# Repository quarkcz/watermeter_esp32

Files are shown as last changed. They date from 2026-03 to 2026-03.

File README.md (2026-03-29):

# Watermeter ESP32 C3
Water meter based on ESP32-C3 - connected to sensor with impulse output.

Published under **[CC BY-NC 4.0](https://creativecommons.org/licenses/by-nc/4.0/legalcode.txt)**

This project was created to have home-made water metering based on [Mikromarz pulse sensor](https://www.mikromarz.com/www-mikromarz-cz/eshop/50-1-Vodomery/172-1-Bytove-vodomery/5/898-Impulsni-modul-pro-vodomery-ENBRA-ER-AM). This sensor requires 5V input, sends a 3.3V logic output signal and is built as open-drain solution (standard output is 3.3V, when impulse, output pin is pulled to GND). If you have a different sensor, feel free to adjust the input part/code. If you have the same one, I recommend to do at least the basic input filtering as I did - tested for several months and works perfect. To have a full control over collected data, software in ESP is not calling directly HomeAssistant, but customizable API. In my case I have a PHP script on my VPS that water meter ESP is connecting to. This PHP script stores the data to MySQL database, where it's read by another PHP script returning raw data and with Python script I get finally a JSON for my HomeAssistant. **Sorry for the complicated architecture - you can of course make it easier - I've used already existing platforms I have access to and since my original solution was connected to Mikromarz cloud, I've reused part of the code reading from the original cloud.**

```
Architecture:
Water sensor -> Water meter -> PHP API -> MySQL -> PHP script -> Python script ->  Home Assistant
```

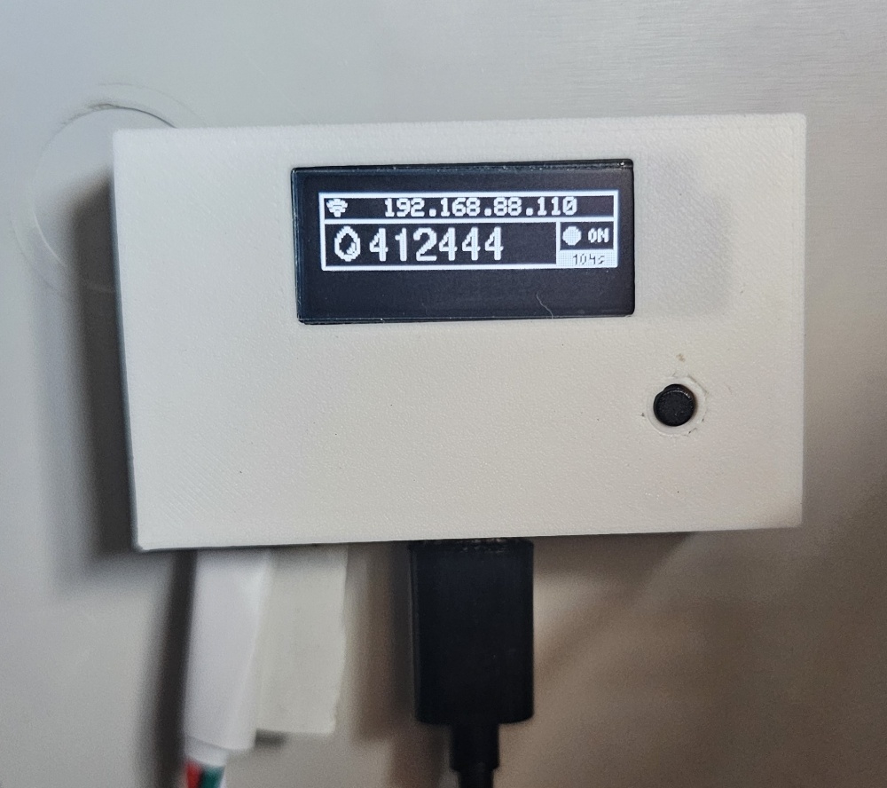
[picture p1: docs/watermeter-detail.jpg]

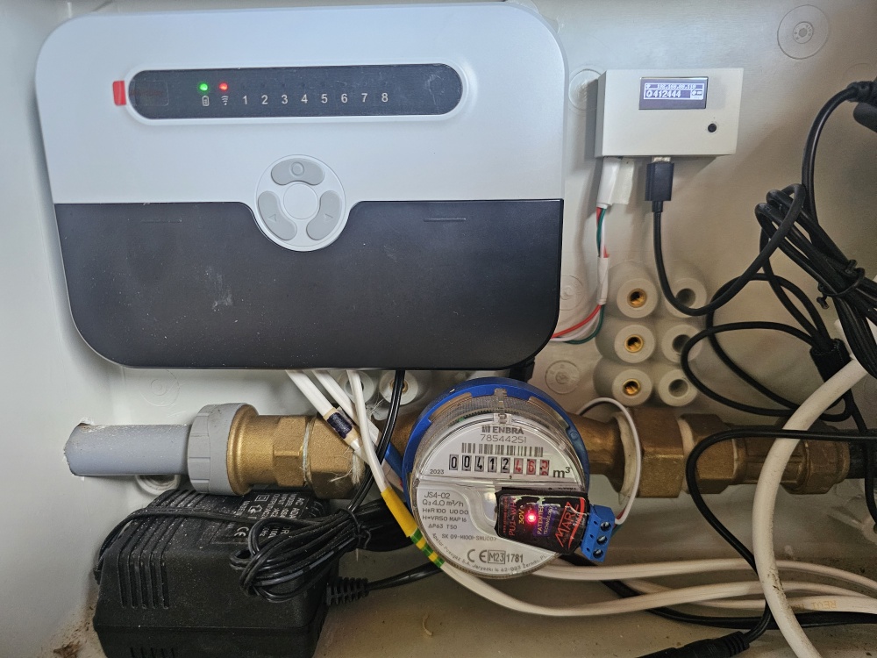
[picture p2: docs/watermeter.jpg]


## Required components
* [ESP32 C3 Zero](https://es.aliexpress.com/item/1005006583420105.html)
* [OLED display 0.91"](https://es.aliexpress.com/item/1005008918700196.html)
* Resistors 1k&Omega;, 10k&Omega;
* Capacitor 100nF
* [Micropush button 6x6x12](https://es.aliexpress.com/item/1005006046180384.html)
* Wires

## Flashing ESP32
Code is written with Arduino architecture, but I've used VS Code with PlatformIO to upload it. LittleFS is used for storing HTML and CSS
1. General -> Full Clean
2. General -> Build (to test if your libraries and dependencies downloaded)
3. Platform -> Build file system image
4. Platform -> Upload file system image
5. Update source code `src/main.cpp` based on your needs (default server/api/...)
6. Build and upload code

## HW assembly
After the firmware upload, disconnect ESP32 and it's time to make HW part.
Ideally print the Enclosure from [3D model published in 3MF](3d/Watermeter%20ESP32%20C3%20zero%20box.3mf). 
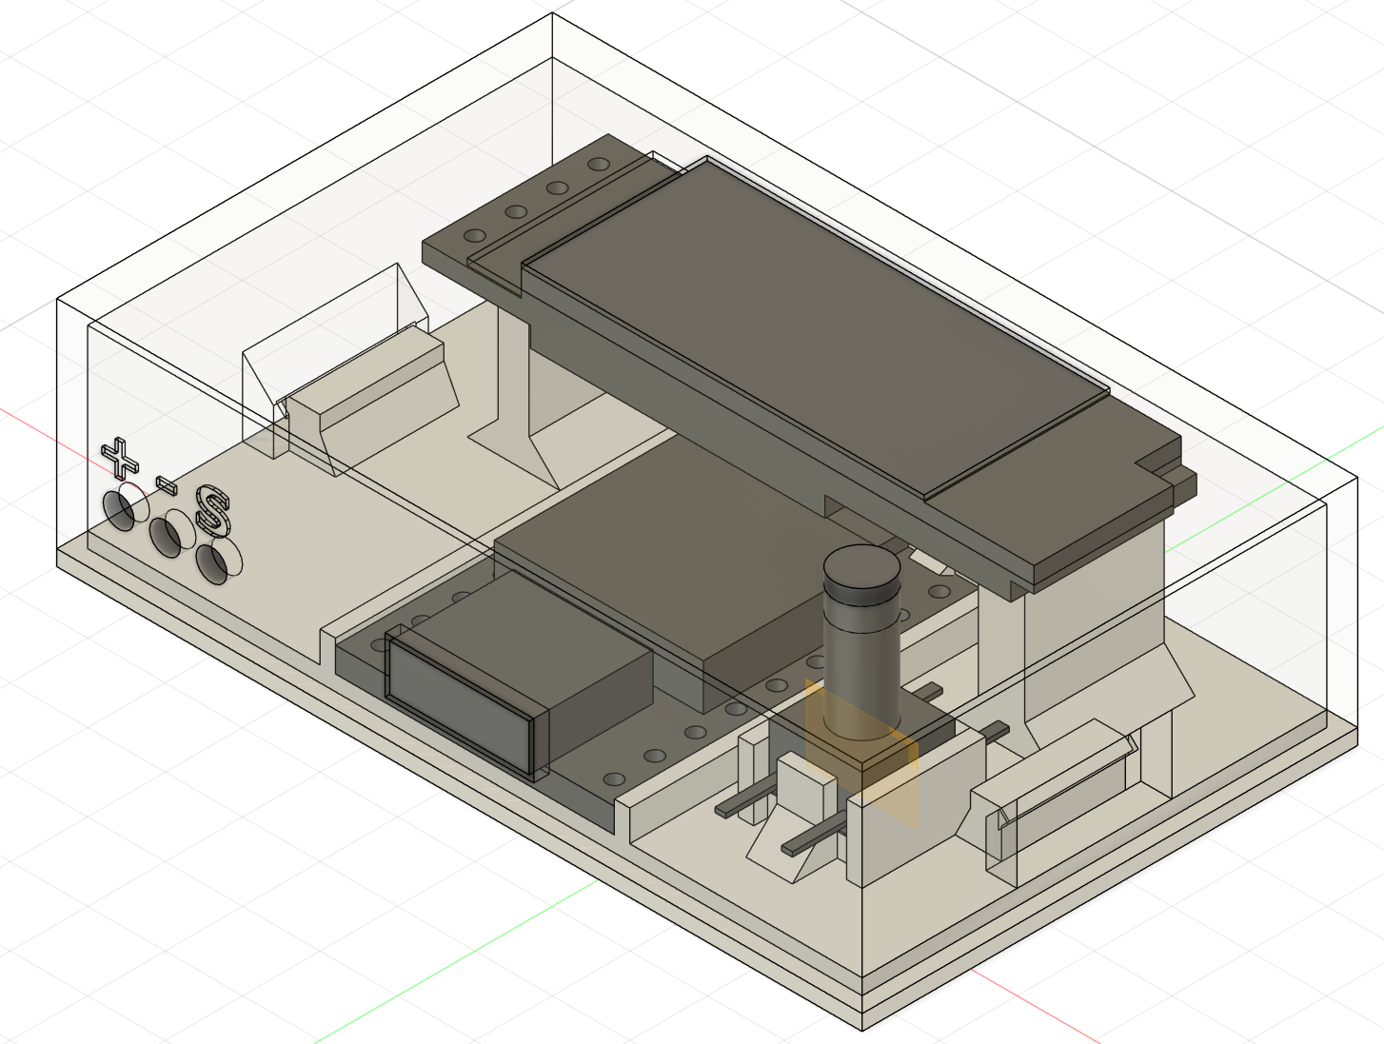
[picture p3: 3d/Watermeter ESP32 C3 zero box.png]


Overall schematics:
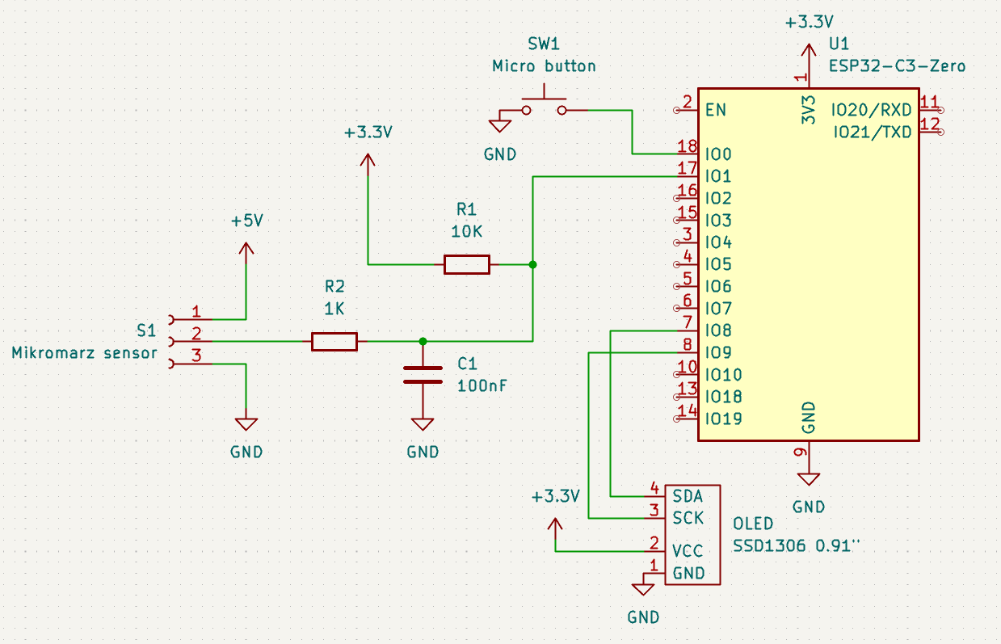
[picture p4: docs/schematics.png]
HW schematics


For filtering input signals - eliminating ghost readings, one of the working (tested) methods is to use schematics ^^^. For connecting the HW, you need to solder two resistors and capacitor + connect the display and microbutton. One of the possible ways that'll fit into the 3D model minimalistic box:

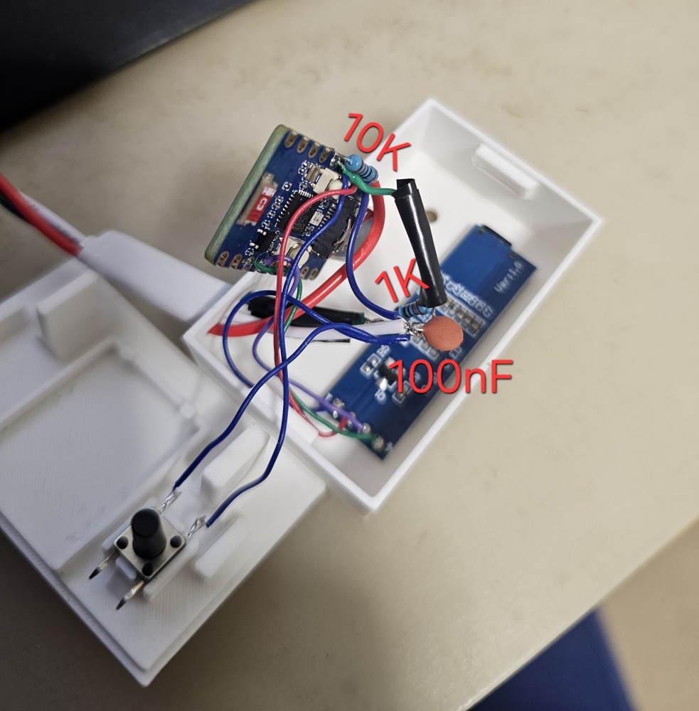
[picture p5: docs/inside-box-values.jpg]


Connection to Mikromarz sensor is simple:
* 5V from ESP32 USB
* GND connected to ESP32 GND
* Pulse connected to 1k resistor (see schematics)

## API part (PHP + MySQL/MariaDB + Python)
For API, I've used simple MySQL/MariaDB tables and PHP script to write data and to read data. Then Python script to return JSON for Home Assistant. 
1. On your server create database for sensors ([table structures](php/sensors-db-structure.sql))
2. Update credentials in PHP scripts `php/sensor-data.php` and `php/sensor-read.php` (in both scripts `mysqli('localhost', 'db_user', 'db_pass', 'db_name');`)
3. Configure your HTML server (i.e. Apache) to execute PHP scripts
4. Create alias for Python script (+ setup webserver to execute Python). For Apache, configuration is like this
````
  <Directory /var/www/html/voda>
    WSGIApplicationGroup %{GLOBAL}
    Order deny,allow
    allow from all	
  </Directory>
  WSGIScriptAlias /voda_spotreba /var/www/html/voda/spotreba.py
````

## First run
If you did everything correctly, after a first run (USB connected), the display will show you SSID and Password for Wifi to connect to. Use your phone/computer to connect to this network and setup your home wifi. After that, you'll see assigned IP on the display.
Connect to this IP and finish the setup - set parameters for API, keys, ...
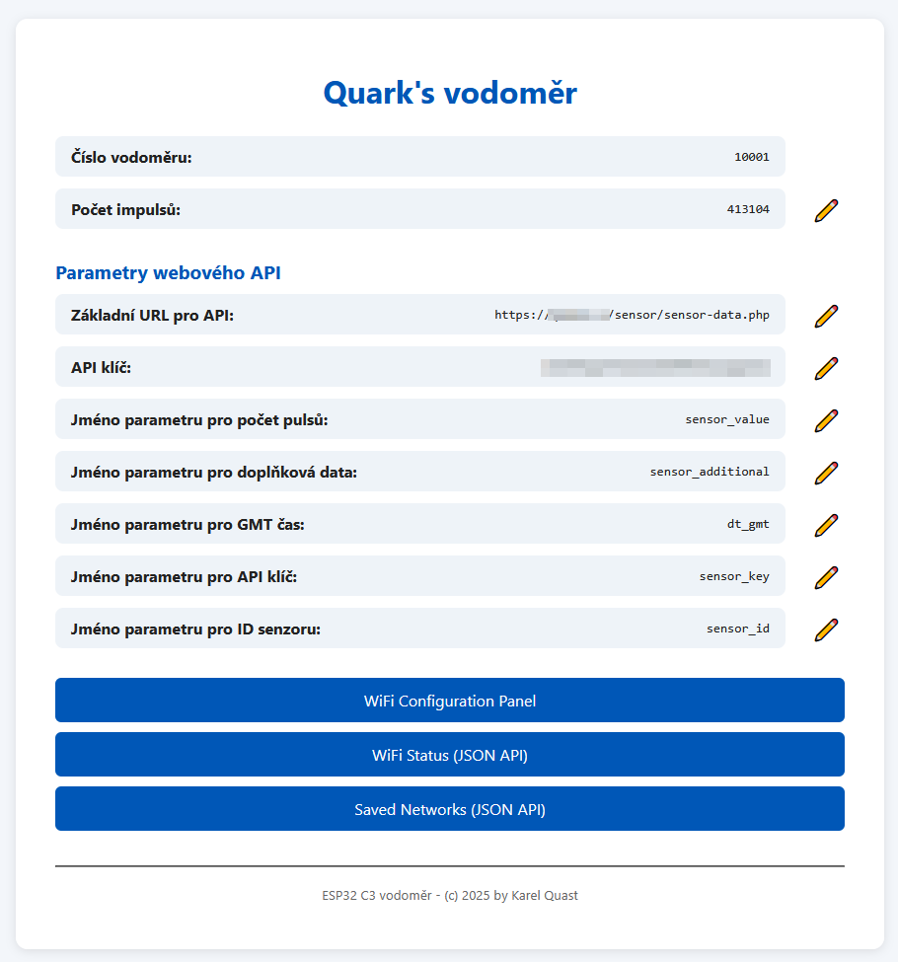
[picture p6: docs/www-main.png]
WWW interface example


*Note:*
For setting up different sensor ID, there's a special URL to change that - not available from GUI. 
`http://192.168.xx.yy/api/syssetup?key=your_calculated_sha3_256_in_hex_build_in_code&vodomer_id=0001`
In this example, `192.168.xx.yy` means your water meter's IP address and `your_calculated_sha3_256_in_hex_build_in_code` is a hash of your secret key stored in `main.cpp` in `/api/syssetup` section.

## Home Assistant integration
If you have working server part (you can call i.e. `https://your-server.com/voda_spotreba` and it returns JSON), you can simple integrate water meter to your Home Assistant by adding following lines to configuration.yaml:
```
rest:
  - resource: https://your-server.com/voda_spotreba
    method: GET
    scan_interval: 300   # every 5 min
    timeout: 8
    sensor:
      - name: "Water home"
        unique_id: water_home
        value_template: "{{ value_json.spotreba_24h | int }}"  # what you want as main entity
        unit_of_measurement: "L"
        device_class: volume
        json_attributes:
          - min_date
          - max_date
          - date_diff_h
          - min_value
          - max_value
          - spotreba_celkem
          - date_from_2h
          - date_to_2h
          - spotreba_2h
          - date_from_12h
          - date_to_12h
          - spotreba_12h
          - date_from_24h
          - date_to_24h
          - spotreba_24h
```

HA dashboard example:

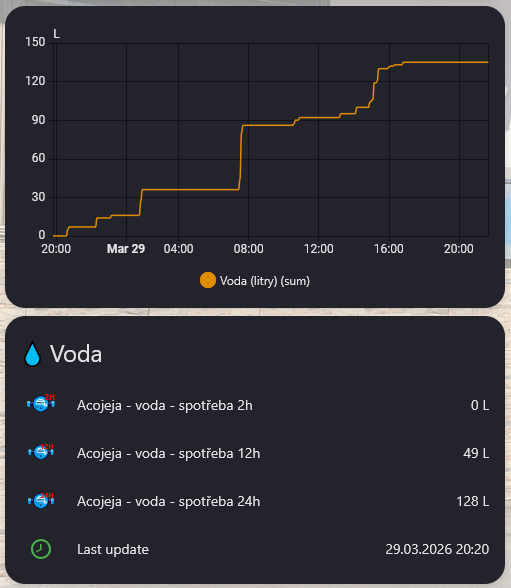
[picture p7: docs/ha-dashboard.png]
Home Assistant dashboard example


## Final words
I know, architecture could be simpler, as I wrote at the beginning, this has it's historical reason. If you would have time to write PHP script to return JSON like python script does, feel free to contact me, I'd be happy to skip Python part and add your script here with attribution :-)

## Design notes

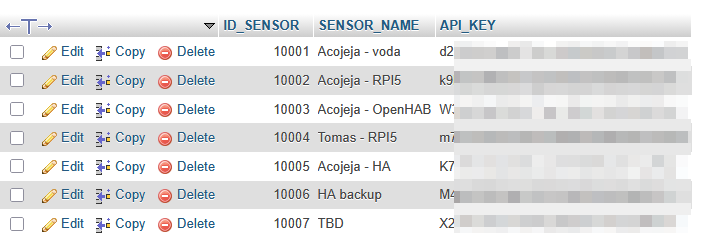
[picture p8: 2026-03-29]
docs/mysql-table-sensor.png

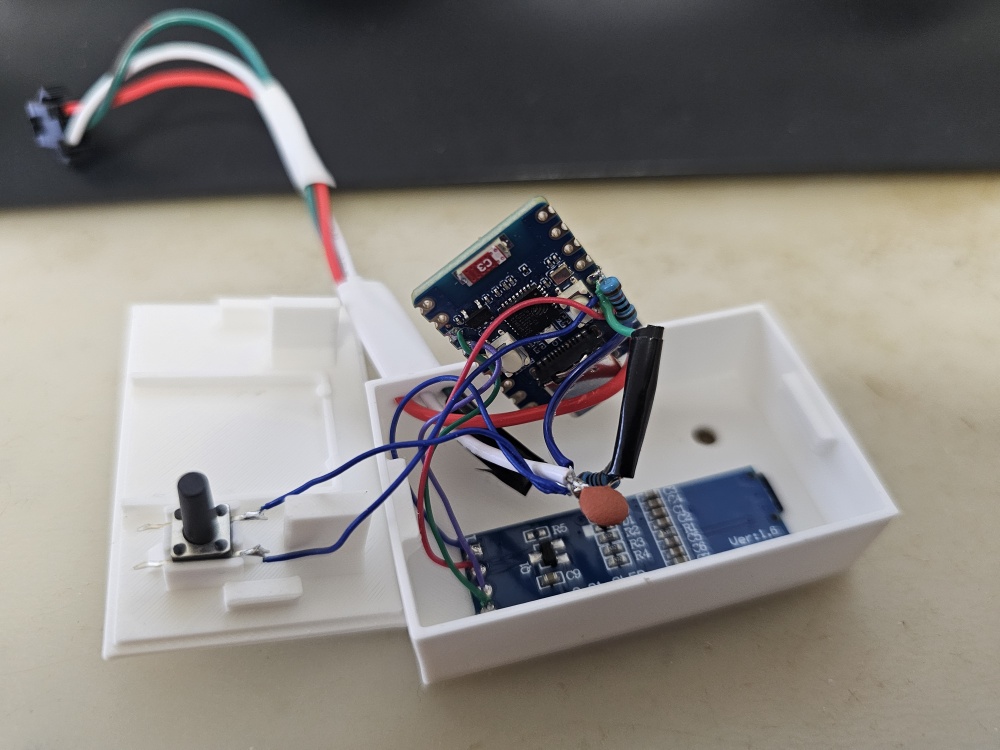
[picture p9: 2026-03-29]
docs/inside-box.jpg

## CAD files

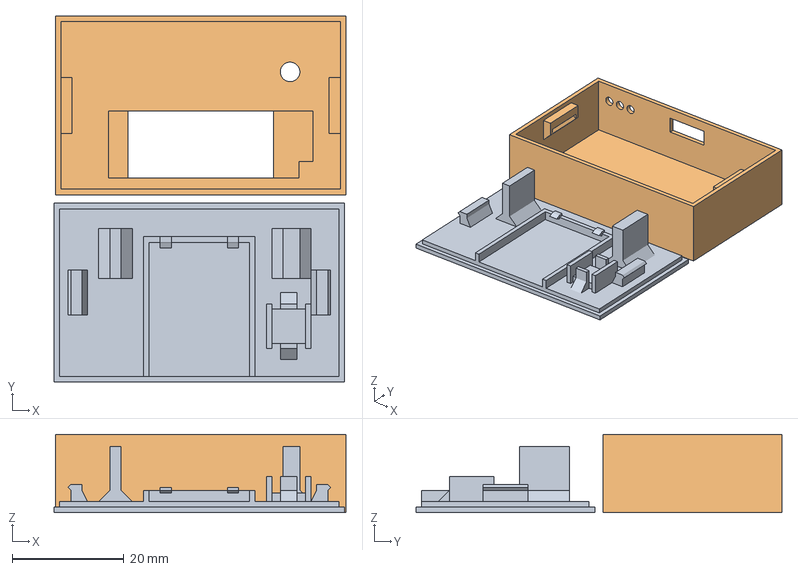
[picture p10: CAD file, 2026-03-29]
3d/Watermeter ESP32 C3 zero box.3mf
52.2 x 65.5 x 14.0 mm

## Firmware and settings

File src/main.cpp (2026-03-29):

/**
 * ESP32 Water Meter
 * @author Karel Quast <karel@quast.cz>
 * @copyright 2026
 * @brief Water meter based on ESP32 for impulse sensor with open-draing architecture
 *
 * Attribution: ESP32 Wifi Manager, Martin Verges <martin@verges.cc>
 *
 * Licensed under CC BY-NC-SA 4.0
**/

#include <Arduino.h>
#include <vodomer.h>
#include <wifimanager.h>
#include <LittleFS.h>
#include <Wire.h>
#include <ESPAsyncWebServer.h>
#include <Preferences.h>
#include <Adafruit_GFX.h>
#include <Adafruit_SSD1306.h>
#include <Fonts/Picopixel.h>
#include <Fonts/FreeSans9pt7b.h>
#include <Fonts/FreeMonoBold9pt7b.h>
#include <esp_wifi.h>  // ESP-IDF API
#include <time.h>
#include <HTTPClient.h>
#include <WiFiClient.h>
#include <WiFiClientSecure.h>
#include <SHA3.h>
#include <ikony.h>

#define SDA_PIN 8
#define SCL_PIN 9
#define SCREEN_WIDTH 128
#define SCREEN_HEIGHT 32
#define PIN_RESET_BUTTON 0
#define PIN_CITAC 1
#define DEBOUNCE_MS 50
#define LONG_PRESS_MS 8000

const char* cVodomerState = VODOMER_STATE_INIT;
const unsigned int cDisplayOnTimeSeconds = 120;
uint32_t cDisplayOnTimeStart = 0;
uint32_t cLastTimeSyncMillis = 0;
const unsigned int cSyncTimeIntervalSeconds = 12 * 60 * 60; //12h
bool cDisplayIsOn = false;
String cVodomerID = "????";
String ap_password = "waterm123";
const String ap_ssid_prefix = "waterm_";
String ap_ssid;
bool vBtnShortPressed = false;
SHA3_256 sha3;

static bool timeSynced = false;
static const char* NTP1 = "pool.ntp.org";
static const char* NTP2 = "time.google.com";
const char* TZ_GMT = "GMT0";

int cButtonLongPressRemainingTimeSeconds = 0;  // zbývající sekundy do LONG_PRESS_MS
volatile bool cIsReseting = false;             // true po začátku držení pro dlouhý stisk
volatile bool btnPressed = false;              // true while button is held
volatile uint32_t pressStartMs = 0;            // time when button went LOW
volatile uint32_t lastEdgeMs = 0;              // for debounce - reset btn
volatile uint32_t lastVodomerEdgeMs = 0;       // for debounce - vodomer counter
volatile bool longFired = false;               // to fire long press only once
volatile long vVodomerCounter = 0;             // hlavní počítadlo pulzů
long vVodomerCounterLastSaved = 0;             // jaká hodnota byla naposledy uložena do paměti
volatile bool vVodomerImpulsePressed = false;  // jestli je vstup z čisla aktivní nebo neaktivní

long vDBVodomerCounterLastSent = 0;            // jaká hodnota byla naposledy poslána do databáze
int cDBSaveIntervalSecondsMin = 10;            // jak často se má volat script pro uložení do vzdálené databáze - nejkratší úsek
int cDBSaveIntervalSecondsMax = 30*60;         // jak často se má volat script pro uložení do vzdálené databáze - nejdelší úsek po kterém se vždy zapíše i beze změny počítadla (keep alive)
uint32_t cDBSaveLastCallMillis = 0;            // kdy bylo naposledy úspěšně uloženo do databáze

String cDBAPIURLBaseDefault = "https://your-server.com/sensor/sensor-data.php";
String cDBAPIURLBase = "";
String cDBAPISensorValueName = "";
String cDBAPISensorValueNameDefault = "sensor_value";
String cDBAPISenrodAdditional = "";
String cDBAPISenrodAdditionalDefault = "sensor_additional";
String cDBAPISensorGMT = "";
String cDBAPISensorGMTDefault = "dt_gmt";
String cDBAPISensorSendKeyAttrName = ""; 
String cDBAPISensorSendKeyAttrNameDefault = "sensor_key"; 
String cDBAPISensorSendKey = ""; //no default
String cDBAPISensorSensorIDAttrName = ""; 
String cDBAPISensorSensorIDAttrNameDefault = "sensor_id";
String vDBAPIUrlToSend = "";

WIFIMANAGER WifiManager;
AsyncWebServer webServer(80);
Adafruit_SSD1306 display(SCREEN_WIDTH, SCREEN_HEIGHT, &Wire, -1);
Preferences prefs;

bool isNumber(const String &str) {
    if (str.length() == 0) return false;
    const char *cstr = str.c_str();
    char *endptr;
    strtol(cstr, &endptr, 10);  // pokus o převod na číslo (základ 10)
    return (*endptr == '\0');   // pokud endptr ukazuje na konec, je to čisté číslo
}

void syncTimeFromNtpIfConnected() {
    if (WiFi.status() != WL_CONNECTED) return;
    Serial.print("[TIME] Synchronizing time...");

    timeSynced = false;

    // Nastaví časové pásmo a spustí SNTP klienta
    configTzTime(TZ_GMT, NTP1, NTP2);

    // Počkej na první synchronizaci (max ~15 s)
    struct tm tmInfo;
    const uint8_t retries = 10;
    for (uint8_t i = 0; i < retries; i++) {
        if (getLocalTime(&tmInfo, 1500)) { // timeout 1.5 s na pokus
            timeSynced = true;
            break;
        }
    }

    if (timeSynced) {
        Serial.printf("... Synced: %04d-%02d-%02d %02d:%02d:%02d\n",
                    tmInfo.tm_year + 1900, tmInfo.tm_mon + 1, tmInfo.tm_mday,
                    tmInfo.tm_hour, tmInfo.tm_min, tmInfo.tm_sec);
        cLastTimeSyncMillis = millis();
    } else {
        Serial.println("... NTP sync failed");
    }
}

String getDateTimeString() {
    struct tm timeinfo;
    if (!getLocalTime(&timeinfo)) {
        return "1970-01-01 00:00:00"; // fallback, když není čas dostupný
    }

    char buf[20]; // "yyyy-mm-dd hh:MM:ss" = 19 znaků + \0
    strftime(buf, sizeof(buf), "%Y-%m-%d %H:%M:%S", &timeinfo);
    return String(buf);
}

void onShortPress() {
    vBtnShortPressed = true;
}

void onLongPress() {
    //Smazat nastavení Wifi manažeru
    Preferences p;
    p.begin("wifimanager", false);
    p.clear();        // smaže všechny klíče v tomto namespace
    p.end();
    Serial.println("[BTN] LONG press -> RESET WIFI!");
    ESP.restart();
}

IRAM_ATTR void handleEdge() {
    uint32_t now = millis();
    if (now - lastEdgeMs < DEBOUNCE_MS) return;
    lastEdgeMs = now;

    bool levelLow = (digitalRead(PIN_RESET_BUTTON) == LOW);
    if (levelLow) {
        // FALLING = pressed
        btnPressed   = true;
        pressStartMs = now;
        longFired    = false;
        cIsReseting  = true;                  
    } else {
        // RISING = released
        bool wasLong = longFired;
        btnPressed = false;
        cIsReseting  = false;                     
        cButtonLongPressRemainingTimeSeconds = 0;   
        if (!wasLong) {
            uint32_t held = now - pressStartMs;
            if (held >= DEBOUNCE_MS) onShortPress();
        }
    }
}

IRAM_ATTR void handleVodomerEdge() {
    uint32_t now = millis();

    vVodomerImpulsePressed = (digitalRead(PIN_CITAC) == LOW);

    if (now - lastVodomerEdgeMs < DEBOUNCE_MS) {
        return;
    }

    if (!vVodomerImpulsePressed) {
        vVodomerCounter++;
    }

    lastVodomerEdgeMs = now;
}

String getSoftAPPassword() {
    wifi_config_t conf{};
    if (esp_wifi_get_config(WIFI_IF_AP, &conf) == ESP_OK) {
        // prázdný string = otevřené AP (bez hesla)
        return String(reinterpret_cast<const char *>(conf.ap.password));
    }
    return String();
}

String sha3256ToHex(const char* input) {
    uint8_t hash[SHA3_256::HASH_SIZE];
    sha3.reset();
    sha3.update((const uint8_t *)input, strlen(input));
    sha3.finalize(hash, sizeof(hash));

    char buf[SHA3_256::HASH_SIZE * 2 + 1];
    for (size_t i = 0; i < sizeof(hash); i++) {
        sprintf(buf + (i * 2), "%02x", hash[i]); // převod byte -> hex
    }
    buf[sizeof(hash) * 2] = '\0';
    return String(buf);
}

// Povolené znaky v URL ponecháme, ostatní %-enkódujeme.
// Zachováváme : / ? & = % aby se nerozbila struktura URL.
static String urlEncodeUrl(const String &in) {
    String out;
    out.reserve(in.length() * 3); // worst-case
    const char* hex = "0123456789ABCDEF";

    auto isAllowed = [](char c) -> bool {
        // alnum + bezpečné + URL strukturální znaky
        if ((c >= 'A' && c <= 'Z') || (c >= 'a' && c <= 'z') || (c >= '0' && c <= '9')) return true;
        switch (c) {
            case '-': case '_': case '.': case '~':
            case ':': case '/': case '?': case '&':
            case '=': case '%': // už může být enkódováno
            return true;
        }
        return false;
    };

    for (size_t i = 0; i < in.length(); ++i) {
        unsigned char c = static_cast<unsigned char>(in[i]);
        if (isAllowed((char)c)) {
            out += (char)c;
        } else {
            out += '%';
            out += hex[(c >> 4) & 0x0F];
            out += hex[c & 0x0F];
        }
    }
    return out;
}

/**
 * Zavolá GET na danou URL (HTTP/HTTPS) s timeoutem 5 s.
 * Vrací true, pokud HTTP 200 a payload je přesně "OK"; jinak false.
 */
bool dbSendData(String url) {
    if (url.length() == 0) return false;
    if (WiFi.status() != WL_CONNECTED) return false;

    HTTPClient http;
    int httpCode = 0;
    String payload;

    http.setTimeout(5000); // 5 s
    http.setFollowRedirects(HTTPC_FORCE_FOLLOW_REDIRECTS);

    // Necháme HTTPClient, ať si podle schématu vybere správný (secure/plain) klient.
    // Tohle je nejspolehlivější i při redirectech mezi http<->https.
    bool begun = http.begin(url);
    if (!begun) {
        Serial.println("[HTTP][ERROR] nepodařilo se inicializovat HTTP klienta pro URL: " + url);
        return false;
    }

    httpCode = http.GET();
    if (httpCode > 0) {
        payload = http.getString();
    } else {
        http.end();
        Serial.println("[HTTP][ERROR] chyba přenosu / timeout (httpCode < 0)");
        return false;
    }

    http.end();

    payload.trim();

    if (httpCode == HTTP_CODE_OK && payload == "OK") {
        return true;
    }
    Serial.printf("[HTTP] code=%d, payload='%s'\n", httpCode, payload.c_str());
    Serial.println("[HTTP][ERROR] Server response: " + payload);
    return false;
}

void drawTextCentered(Adafruit_GFX &disp, String txt, int x1, int x2, int y) {
    int16_t bx, by;
    uint16_t w, h;

    disp.getTextBounds(txt, 0, 0, &bx, &by, &w, &h);

    int areaWidth = x2 - x1;
    int x = x1 + (areaWidth - w) / 2;

    disp.setCursor(x, y);
    disp.print(txt);
}

void displayCurrentState() {
    display.clearDisplay();
    display.setTextSize(1);
    display.setTextColor(SSD1306_WHITE);
    display.setCursor(0, 0);

    if (cIsReseting) {
        display.clearDisplay();
        DrawIcon(display, "danger24x24", 1, 4);  // vykreslí vykřičník vlevo
        display.setCursor(35, 8);
        display.print("FULL RESET in:");
        display.setCursor(35, 20);
        display.print(String(cButtonLongPressRemainingTimeSeconds));
        display.print(" s");
        display.display();
    } else {
        if (WiFi.status() == WL_CONNECTED) {
            // Standardni obrazovka
            display.drawRect(0, 0, SCREEN_WIDTH, SCREEN_HEIGHT, SSD1306_WHITE);
            DrawIcon(display, "wifi8x7", 3, 2); 
            display.setCursor(12, 2);
            drawTextCentered(display, WiFi.localIP().toString(), 12, SCREEN_WIDTH - 2, 2);

            display.drawLine(0, 11, SCREEN_WIDTH, 11, SSD1306_WHITE);
            DrawIcon(display, "water_drop16x16", 3, 13);  

            //Pocet pulzu
            if (vVodomerCounter <= 99999999) {
                display.setCursor(19, 21);
                display.setFont(&FreeSans9pt7b);
                display.print(vVodomerCounter);
            } else {
                display.setCursor(20, 18);
                display.setFont(nullptr);
                display.setTextSize(1);
                display.print(vVodomerCounter);
            }

            display.setTextSize(1);
            display.setFont(&Picopixel);
            display.drawLine(SCREEN_WIDTH - 26, 11, SCREEN_WIDTH - 26, SCREEN_HEIGHT - 7, SSD1306_WHITE);
            if (vVodomerImpulsePressed) {
                drawTextCentered(display, "ON", SCREEN_WIDTH - 16, SCREEN_WIDTH, 20); 
                display.fillCircle(SCREEN_WIDTH - 20, 18, 3, SSD1306_WHITE);
            } else {
                drawTextCentered(display, "OFF", SCREEN_WIDTH - 16, SCREEN_WIDTH, 20);
                display.drawCircle(SCREEN_WIDTH - 20, 18, 3, SSD1306_WHITE);
            }
            display.setFont(nullptr);
        } else if (WiFi.getMode() & WIFI_AP) {
            // Přístupový bod
            DrawIcon(display, "wifi_cover24x24", SCREEN_WIDTH - 25, 0); 

            DrawIcon(display, "four_dots_narrow16x5", 1, 3); 
            display.setCursor(20, 1);
            display.println(WiFi.softAPIP());

            DrawIcon(display, "wifi8x7", 4, 12); 
            display.setCursor(20, 12);
            display.println(WiFi.softAPSSID());

            DrawIcon(display, "lock_2", 4, 23); 
            display.setCursor(20, 23);
            display.println(getSoftAPPassword());
        } else {
            // Není ani WiFi ani AP
            DrawIcon(display, "wifi_no_signal24x24", 1, 4);  // vykreslí vykřičník vlevo
            display.setCursor(28, 16);
            display.setFont(&FreeSans9pt7b);
            display.println("No WiFi");
            display.setFont(nullptr);
        }

        int remSec = cDisplayOnTimeSeconds - ((millis() - cDisplayOnTimeStart) / 1000);
        display.fillRect(SCREEN_WIDTH - 26, SCREEN_HEIGHT - 7, SCREEN_WIDTH, SCREEN_HEIGHT, SSD1306_WHITE);
        display.setFont(&Picopixel);
        display.setTextColor(SSD1306_BLACK);
        drawTextCentered(display, String(remSec) + "s", SCREEN_WIDTH - 24, SCREEN_WIDTH, SCREEN_HEIGHT - 2);
        display.setFont(nullptr);
        display.setTextColor(SSD1306_WHITE);
    }

    display.display();
}

void readPrefferences() {
    prefs.begin("vodomer", false); 

    cVodomerID = prefs.getString("cVodomerID", "9999");
    vVodomerCounter = prefs.getLong("vVodomerCounter", 0);

    cDBAPIURLBase = prefs.getString("APIURLBase", cDBAPIURLBaseDefault);
    cDBAPISensorValueName = prefs.getString("APIValueName", cDBAPISensorValueNameDefault);
    cDBAPISenrodAdditional = prefs.getString("APIAdditional", cDBAPISenrodAdditionalDefault);
    cDBAPISensorGMT = prefs.getString("cAPIGMT", cDBAPISensorGMTDefault);
    cDBAPISensorSendKey = prefs.getString("APISendKey", "");
    cDBAPISensorSendKeyAttrName = prefs.getString("APISendKeyAttrName", cDBAPISensorSendKeyAttrNameDefault);
    cDBAPISensorSensorIDAttrName = prefs.getString("APIIDAttrName", cDBAPISensorSensorIDAttrNameDefault);

    prefs.end();
}
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
void loop() {
    delay(300);

    if (vBtnShortPressed) {
        vBtnShortPressed = false;
        Serial.println("[BTN] short press -> turning display ON");
        cDisplayOnTimeStart = millis();
        if (!cDisplayIsOn) {
            cDisplayIsOn = true;
            display.ssd1306_command(SSD1306_DISPLAYON);
        }
    }

    if (cDisplayIsOn == true) {
        displayCurrentState();
    }

    if (btnPressed && !longFired) {
        uint32_t now = millis();
        if (now - pressStartMs >= LONG_PRESS_MS) {
            longFired = true;
            onLongPress();
        }
    }
    if (btnPressed && !longFired) {
        uint32_t now = millis();
        // aktualizace zbývajících sekund do dlouhého stisku
        int32_t remainingMs = (int32_t)LONG_PRESS_MS - (int32_t)(now - pressStartMs);
        if (remainingMs < 0) remainingMs = 0;
        // zaokrouhlení nahoru na celé sekundy (ceil)
        cButtonLongPressRemainingTimeSeconds = (remainingMs + 999) / 1000;

        if (now - pressStartMs >= LONG_PRESS_MS) {
            longFired = true;
            cIsReseting = false; // kosmeticky; stejně se hned restartuje
            onLongPress();       // ESP.restart()
        }
    }    

    //Je treba ulozit do vnitrni pameti posledni stav pocitadla?
    if ((vVodomerCounterLastSaved != vVodomerCounter) && (vVodomerCounter != 0)) {
        prefs.begin("vodomer", false); 
        prefs.putLong("vVodomerCounter", vVodomerCounter);
        vVodomerCounterLastSaved = vVodomerCounter;
        prefs.end();       
    }

    //Neni treba vypnout display?
    if ((cDisplayIsOn == true) && (millis() - cDisplayOnTimeStart > cDisplayOnTimeSeconds * 1000)) {
        cDisplayIsOn = false;
        Serial.println("Turning display off...");
        display.ssd1306_command(SSD1306_DISPLAYOFF);
    }

    //Neni treba synchronizovat cas?
    if ((millis() - cLastTimeSyncMillis > cSyncTimeIntervalSeconds * 1000) || (cLastTimeSyncMillis == 0)) {
        syncTimeFromNtpIfConnected();
    }

    //Neni treba zapsat do DB?
    if (
        (((vDBVodomerCounterLastSent != vVodomerCounter) && (millis() - cDBSaveLastCallMillis > cDBSaveIntervalSecondsMin * 1000)) || (cDBSaveLastCallMillis == 0)) 
        ||
        (millis() - cDBSaveLastCallMillis > cDBSaveIntervalSecondsMax * 1000)
       )
    {
        String vPulse = urlEncodeUrl((vVodomerImpulsePressed == true) ? "Pulse=ON" : "Pulse=OFF");
        vDBAPIUrlToSend = cDBAPIURLBase + "?" 
            + cDBAPISensorSendKeyAttrName + "=" + cDBAPISensorSendKey
            + "&" + cDBAPISensorSensorIDAttrName + "=" + cVodomerID
            + "&" + cDBAPISensorValueName + "=" + String(vVodomerCounter) 
            + "&" + cDBAPISensorGMT + "=" + urlEncodeUrl(getDateTimeString()) 
            + "&" + cDBAPISenrodAdditional + "=" + vPulse;

        Serial.print("Volám API... ");
        if (dbSendData(vDBAPIUrlToSend)) {
            vDBVodomerCounterLastSent = vVodomerCounter;
            Serial.println("...done (OK)");
        } else {
            Serial.println("...error!");
            //Serial.println(vDBAPIUrlToSend); //DEBUG ONLY
        }
        cDBSaveLastCallMillis = millis();
    }
   
}
